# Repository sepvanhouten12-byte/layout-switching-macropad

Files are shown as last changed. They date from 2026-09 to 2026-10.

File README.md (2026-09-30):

# layout switching macropad

this is my custom macropad that switches layouts with faders and is planned to use kmk firmware.

it has 15 keys in a 3x5 matrix and 3 faders. the idea is that one of the faders can switch between layouts, so the same keys can do different things depending on the position of the slider.

## features

- 15 mechanical keys in a 3x5 layout
- 3 faders for layout switching and other controls
- raspberry pi pico 2w as the microcontroller
- rechargeable battery setup
- custom pcb
- 3d printed case
- expansion headers for possible future additions
- programmable in python with kmk

## files

- [JOURNAL.md](JOURNAL.md) - the full project journal
- [docs/ASSEMBLY.md](docs/ASSEMBLY.md) - assembly notes
- [cad/](cad/) - case and other cad files
- [production/](production/) - files needed for pcb production
- [bom.csv](bom.csv) - bill of materials
- [PCB_Z_PCB_macropad-pcb_2026-09-25.json](PCB_Z_PCB_macropad-pcb_2026-09-25.json) - pcb file
- [X_Schematic_macropad-pcb_2026-09-09.pdf](X_Schematic_macropad-pcb_2026-09-09.pdf) - schematic pdf
- [Y_layout%20changing%20macropad%20case.step](Y_layout%20changing%20macropad%20case.step) - case step file

## design

the pcb uses a switch matrix with diodes to help prevent ghosting. it is a 4-layer pcb, with the two inner layers used as ground and 3v3 planes.

there are also spare pins on female headers for possible future expansions. the pcb is 120mm x 140mm, and the case is designed to be 3d printed around it.

## pictures

### pcb design

pcb design

pcb routing

## BOM

| Item | Vendor | Qty | Unit price | Total price |
| --- | --- | ---: | ---: | ---: |
| Raspberry Pi Pico 2WH | Otronic | 1 | €11.95 | €11.95 |
| 2 Channel Linear Fader 75mm 10k | Otronic | 3 | €2.30 | €6.90 |
| 1N4148 diode | Otronic | 15 | €0.15 | €2.25 |
| 40-pin female header | Otronic | 3 | €0.65 | €1.95 |
| 3.7V rechargeable 4000mAh LiPo battery | Otronic | 1 | €10.95 | €10.95 |
| TP4056 charging and protection circuit | Otronic | 1 | €2.40 | €2.40 |
| Gateron KS-3X1 switches | Gateron | 1 set | €9.10 | €9.10 |
| 5x custom PCBs | JLCPCB | 1 | €43.30 | €43.30 |
| Shipping and discount | Various | 1 |  | €29.41 |
| **Grand total** |  |  |  | **€115.60** |

For the full bill of materials, see [bom.csv](bom.csv).

## design link

- [Tinkercad case model](https://www.tinkercad.com/things/2xOaqvWOUL6-layout-changing-macropad-case)

## license

this project uses the cc0 license.

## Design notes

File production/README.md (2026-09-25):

# production files

this folder is for everything needed to make the pcb

there is no dedicated BOM because all the parts in the PCB are user contributed

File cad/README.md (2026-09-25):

# cad files

this folder is for the case and other cad files

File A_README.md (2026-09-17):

hello this is my repo for my layout switching macropad
here is a short description of my project more info is obtainable in the JOURNAL.md section

so I am making a programmable macropad you can code in python and uses the raspberri pi pico 2wh from otronic
it will be rechargable and use Bluetooth the keyboardd part uses a 3x5 switch matrix and there will be 3 faders
you can program the faders how you want but my plan is to make 1 of them switch the things the matrix does based on its position
it will have a 3d printed case and keycaps and I will use the acetone trick on the keycaps to get them nice and shiny

here are some screenshots of the datasheet and the finished PCB gerber





as microcontroller it uses the raspberri pi pico 2w 
and the pcb is 120 by 140 mm

also here is the tinkercad link for my model
https://www.tinkercad.com/things/2xOaqvWOUL6-layout-changing-macropad-case

here is the picture in jlcpcb of the pcb



BOM

| Item Description | Vendor | Qty | Unit Price | Total Price | Link |
| :--- | :---: | :---: | :---: | :---: | :--- |
| Raspberry Pi Pico 2WH | Otronic | 1 | €11.95 | €11.95 | [Link](https://otronic.nl) |
| 2 Channel Linear Fader 75mm 10k | Otronic | 3 | €2.30 | €6.90 | [Link](https://otronic.nl) |
| Diode 1N4148 Max 100V 200mA | Otronic | 15 | €0.15 | €2.25 | [Link](https://otronic.nl) |
| 40 Pins Header Female 2.54mm (OT156-B126) | Otronic | 3 | €0.65 | €1.95 | [Link](https://otronic.nl) |
| 3.7V Rechargeable 4000mAh LiPo Battery | Otronic | 1 | €10.95 | €10.95 | [Link](https://otronic.nl) |
| TP4056 Lithium Battery Charging & Protection Circuit | Otronic | 1 | €2.40 | €2.40 | [Link](https://otronic.nl) |
| Shipping Costs (Otronic) | Otronic | 1 | €6.99 | €6.99 | - |
| **Otronic Subtotal** | | | | **€43.39** | |
| | | | | | |
| Gateron KS-3X1 Milky Yellow Red Pro Switch Set | Gateron | 1 | €9.10 | €9.10 | [Link](https://gateron.co) |
| Shipping Costs (Gateron) | Gateron | 1 | €4.90 | €4.90 | - |
| **Gateron Subtotal** | | | | **€14.00** | |
| | | | | | |
| 5x Custom PCBs (120x140mm, 4-Layer, 1.6mm, Black) | JLCPCB | 1 | €43.30 | €43.30 | [Link](https://jlcpcb.com) |
| Shipping Costs (JLCPCB) | JLCPCB | 1 | €24.91 | €24.91 | - |
| Coupon Discount | JLCPCB | 1 | -€10.00 | -€10.00 | - |
| **JLCPCB Subtotal** | | | | **€58.21** | |
| | | | | | |
| **Grand Total** | | | | **€115.60** | |

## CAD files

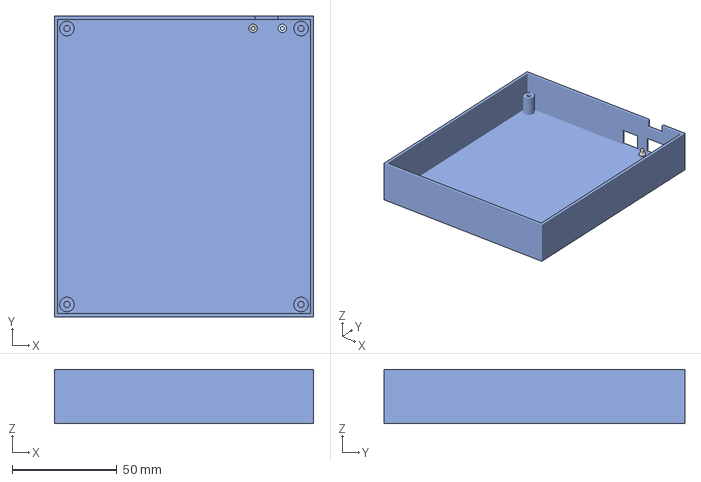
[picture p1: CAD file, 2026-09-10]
cad/layout changing macropad case.step
123.8 x 143.8 x 26.0 mm

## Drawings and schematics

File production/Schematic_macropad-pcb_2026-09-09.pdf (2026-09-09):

G15 20 G16 21 G17 22 GND 23 G18 24 G19 25 G20 26 G21 27 GND 28 G22 29 RUN 30 G26 31 G27 32 GND 33 G28 34 VREF 35 3V3 36 3V3_EN 37 GND 38 VSYS 39 VBUS 40

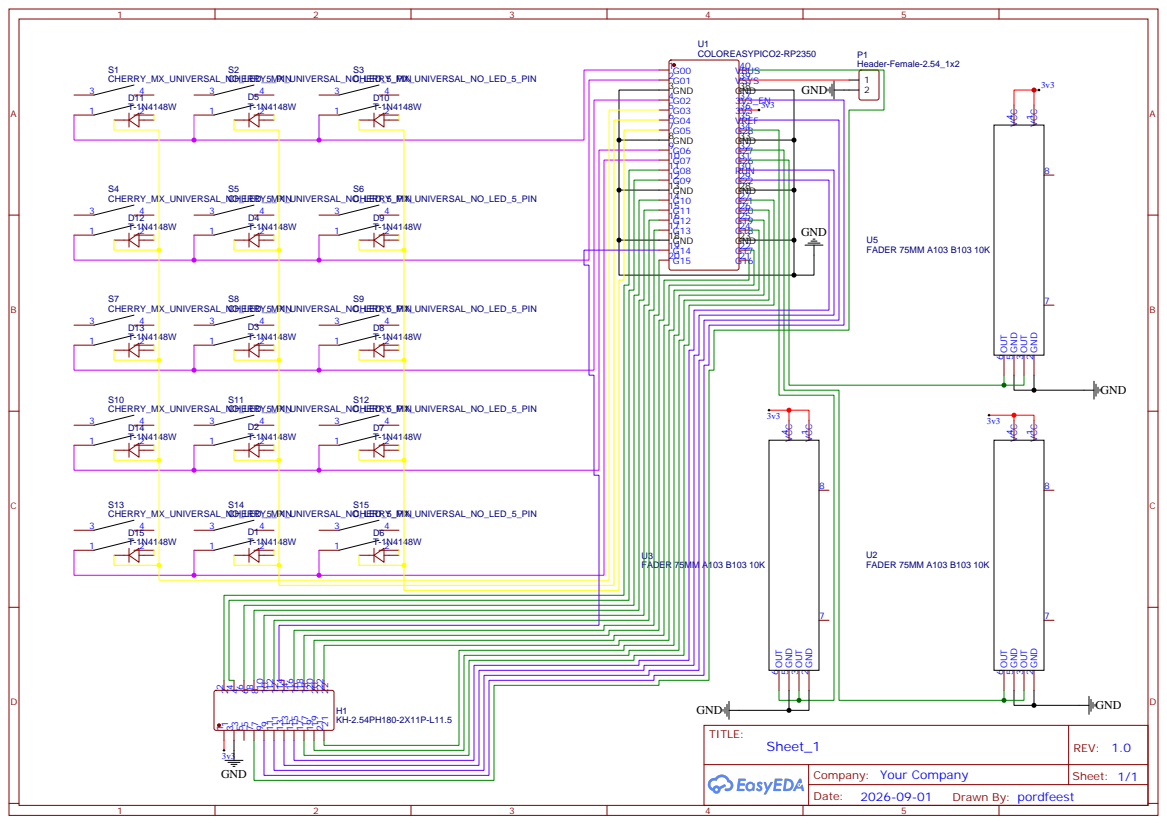
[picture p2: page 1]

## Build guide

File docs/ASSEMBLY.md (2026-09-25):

# assembly notes

these are my current notes for putting the macropad together

i have not finished building the final version yet so some things can still change

## parts

- pcb
- 3d printed case
- raspberry pi pico 2w or 2wh
- 15 switches
- 15 1n4148 diodes
- 3 linear faders
- female headers
- tp4056 charging board
- battery

The full list is in the [bom](../bom.csv)

## build order

1. solder the diodes onto the pcb and check that they face the right way
2. solder the switches
3. check the switch matrix with a multimeter
4. add the three faders
5. add the pico headers and extra headers
6. check power and ground before connecting anything
7. **Before mounting the PCB in the case, wire and position the battery and TP4056 as described below.**
8. put the pcb in the case and check the usb and charging ports
9. connect the pico and test the firmware before closing the case

## battery and TP4056 wiring

The battery and charging circuit need extra care. Do this wiring before screwing the PCB into the case:

1. Identify the TP4056 battery pads marked `B+` and `B-`, and the charging-input pads marked `IN+` and `IN-` (sometimes these are labelled `+` and `-`). Do not confuse the battery pads with the input pads.
2. Solder the Li-ion battery's **red wire to `B+`** on the TP4056.
3. Solder the Li-ion battery's **black wire to `B-`** on the TP4056.
4. Use pliers to separate the required number of pins from a larger header strip and make a 2-pin header for the charging-power input. Solder one pin to `IN+` and the other pin to `IN-`. The positive pin must go to `IN+` and the ground/negative pin must go to `IN-`. This header is the power input for the charger; it is not a replacement for the battery connection on `B+`/`B-`.
5. Inspect every solder joint and use a multimeter to verify that positive and negative are not shorted. Check the header polarity against the schematic before applying power or connecting the battery.

Before closing the case, place the TP4056 onto its two 3D-printed locating pins. Lay the battery in the case in its intended position, with the wires routed so they cannot be pinched. Only after the TP4056 and battery are positioned correctly should you place and screw the PCB into the case. Make sure the PCB, screws, and case cannot press on or damage the battery or its wires.

Check the polarity and make sure there are no shorts before connecting the battery or charger power.

The firmware still needs to be added

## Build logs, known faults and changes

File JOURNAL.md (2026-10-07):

layout switching macropad
https://github.com/sepvanhouten12-byte/layout-switching-macropad 
description: a macropad using kmk firmware that switches layouts with faders 
created_at: "2026-09-1"

# September 1st: <chose the parts>

(disclaimer: i worked on this project before in macondo the feedback i got was make a pcb for it so I am taking the feedback and what i learned and now using it here. so that is why I'd would have a higher time than normal on this commit)

i chose my parts for the macropad today 15 keyboaard switches 3 faders and 1 potentiometer my microcontroller is the raspberri pi 2w and my power scource will be a tp4056 with 1 or two 18650 rechargable batteries I also thouroghly researched if the parts where compatible and it should be correct



**Total time spent: 4h**

# September 2nd: PCB

I started making and wiring the PCB
the keyboard switches are wired and I should only have to do do the faders and potentiometer
the keyboard switches all have diodes so I don't get ghosting 
I am using the matrix wiring method to detect Wich key is pressed to save gpio2 with this gpio2 I also would be able to code later expansions




**Total time spent: 3h**

# September 3rd: finishing the pcb

i finished the wiring and did the routing of my pcb
I also found out the raspberri pi pico only has 3 analog inputs so I scrapped the potentiometer
and instead I'm doing just the 15 keyboard switches and 3 faders
I also took the spare pins I had and put them on a 22 pin female headers for later expansions
and took a 1x2 header for vsys and  gnd as power input
also I decided to take a 4 layer PCB and make the 2 middle layers planes for gnd and 3v3 




**Total time spent: 3h**

# September 7th: cad and alignment

today I learned how to set the 0,0 coordinates on my PCB dezing grid so I could align the screw holes nicer 
they are in each corner and 4 mm from the nearest two ends of the pcb
I also started the cad model thee PCB will be mounted on.
last I found out I need to make a minimum of 5 PCBs and it would cost 34-36 euros for production





**Total time spent: 4h**

# September 8th: cad and working on the case

today I worked more on the case for the PCB and chose to let the raspberry pi 2w stick out of the top a bit because I thought it would be an nice asteatic 



**Total time spent: 1h**

# September 9th: bottom of case done

today I finished the bottom part of the case I now have a place for the pico 2w data port a place for the USB c charging port and a hole for the wires of the expansion pin headers to go through but I cant make the top cover yet course I don't know exactly where some of the press able parts for the buttons are and I don't wanna mess t up so I will do that once it is shipped and the parts are here



**Total time spent: 1h**

# September 9th: prices and shipping the project

okay so the project should be ready to ship but before I do that I need to make the shopping karts with the prices also I looked a bit more into my hardware details and found out you cant use kmk with the raspberri pi pico 2w so I will be using other non hack club libraries
but here are the screenshots of my cart 


the pcb



otronic cart


the keyboard swithes

I couldn't get the akko switches cuz they wouldn't have them in stock for like 1 and a half months

total costs: 108.60 euros

**Total time spent: 4h**

# September 10th: finally converted my stl to step

i finally managed to turn my sttl file for the case into a step file 
I tried like 33 stl to step converters and all of them didn't work but a friend had conversion software and converted it for me



**Total time spent: 2h**

# September 14th: finally organized my repo
finally found out how to organize my repo and organized it by putting uppercase letters in front so I get them in the order I wanted

(disclaimer for shipping: I wanted to make and test code but it seems this is impossible because wokwi doesn't have a raspberri pi 2w microcontroller and I don't know another good simulator also no simulator can do Bluetooth connection so the only good and foolproof way to code it is when I have it physically that's why there isn't any code yet.)



**Total time spent: 2h**

# September 17th:made the Gerber a step file
I made my Gerber a step file so that the reviewers coud see it 
and fixed my BOM



**Total time spent: 3h**

# September 18th: fixed readme name
I fixed the name of the readme because I couldn't name it A_README.md for organization couse GitHub uses alfhabetical


**Total time spent: 0.3h**

# September 25th: fixed the file issues and organized the repo
I fixed my file issues and organized my full the build instructions are placed in the docs file and everything should be ready



**Total time spent: 4.7h**

# october 7th: polished the readme and customized the case
over the course of oct 2nd oct 6th and oct 7th I polished the readme a bit
and I customized the case I added its name on the side for the charging cables and stuff and I added a nice groove texture on the side
im thinking about making a attachment point or anchor point so peapole can make attachments



**Total time spent: 4h**

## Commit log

2026-09-01 Add initial project journal entry for macropad
    Documented initial project details for layout switching macropad, including parts selection and time spent.
2026-09-02 Update JOURNAL.md with September 2nd entry
    Document progress on PCB wiring and components.
2026-09-03 Update journal entry for September 3rd
    Documented progress on PCB design and wiring, including changes to component selection and layout.
2026-09-07 Add journal entry for September 7th on PCB design
    Documented learning about PCB design, including setting coordinates and production costs.
2026-09-08 Add journal entry for September 8th
    Document work on the PCB case and Raspberry Pi placement.
2026-09-09 Update JOURNAL.md with September 9th entry
    Document progress on case design and components.
2026-09-09 Add images and details to README
    Updated the README with additional images and details about the Raspberry Pi Pico 2W.
2026-09-09 Add BOM for Otronic, Gateron, and JLCPCB karts
    Added a bill of materials (BOM) for the Otronic kart, Gateron kart, and JLCPCB kart, including itemized costs and totals.
    [bom.csv]
2026-09-09 Add files via upload
    added the bottom part of the case the Gerber of the pcb and the datasheet
    [layout changing macropad case.stl]
2026-09-10 Add entry for STL to STEP file conversion
    Documented the successful conversion of STL to STEP file.
2026-09-10 Update JOURNAL with STL to STEP conversion details
    Documented successful conversion of STL to STEP file after multiple attempts with various converters.
2026-09-14 Rename layout changing macropad case.step to Y_layout changing macropad case.step
    [Y_layout changing macropad case.step]
2026-09-17 Update A_README.md with PCB images and BOM
    Added images of the PCB and BOM section to the README.
2026-09-17 Refactor BOM section into a structured table
    Updated BOM section to a table format with detailed item descriptions, vendors, quantities, unit prices, and total prices.
2026-09-17 Revise BOM to structured table format
    Updated BOM format to a structured table with item details, vendors, quantities, unit prices, and total prices.
    [bom.csv]
2026-09-17 Update bom.csv with new pricing information
    [bom.csv]
2026-09-17 changed PCB to correct file type
2026-09-17 Update JOURNAL.md with STEP file and BOM fixes
    Documented the creation of a STEP file from Gerber and the resolution of BOM issues.
2026-09-17 Revise README with project details and BOM
    Updated project description to include details about the programmable features, Bluetooth capability, and hardware specifications. Added a BOM section with item descriptions and links.
2026-09-24 Revise September 17th journal entry for clarity
    Updated the journal entry for September 17th to clarify the process of creating a STEP file and fixing the BOM.
2026-09-25 Update the README in the original project style and add clear CAD production and assembly notes for the Hack Club review
2026-09-25 Update README.md to remove obsolete case file details
    Removed outdated information about the case file and reviewer feedback.
2026-09-25 Add battery and TP4056 assembly instructions
2026-09-25 Clarify header strip preparation in assembly parts
2026-09-25 Update README.md for production files
    Removed outdated production file instructions and BOM details.
2026-09-25 Outline testing steps for keys, faders, and layout
    Plan the testing sequence for the assembly process.
2026-09-30 Tighten the README wording and add a bit more energy without going too over the top.
2026-09-30 Improve README readability and replace the gallery with the latest PCB, schematic, and case design images from the journal.
2026-09-30 Remove case design section from README
    Removed case design section and associated images from README.
2026-10-07 Add journal entry for October 7th
    Added journal entry for October 7th detailing README polishing and case customization.
2026-10-18 Add final build image to README
    Added final build image without keycaps or case.
2026-10-18 Update journal entry for October 18th
    Documented work on the case lid and final build, including visibility of the Pi Pico and considerations for keycap clearances.
2026-11-06 Update README to reflect the actual CircuitPython firmware and add product links to the BOM and project description.
